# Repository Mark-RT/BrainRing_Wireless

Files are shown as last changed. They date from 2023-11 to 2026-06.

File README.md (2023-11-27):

# BrainRing_Wireless

Разработка для игры BrainRing - беспроводная версия. Количество участников может быть не больше 10, в основном 4. Для устройства ведущего есть прошивка "Admin", а для всех участников прошивка "Players".

Устройства работают на принципе обратной связи, постоянной. То есть Игроки в любой момент времени, даже если была перезагрузка или потеря связи, знают, выиграли они или нет. Этот принцип конечно идёт в ущерб энергопотреблению, но в плюс стабильности работы, так как проверено временем.

По какой-то причине 1 версия перестала работать. Есть подозрение что обновилась библиотека и что-то пошло не так. Поэтому 2-я версия усовершенствованная (иногда были проблемы что игроки вместе нажимали на кнопку и ни у кого не сработало) и на всякий случай оставляю библиотеку которая точно работала на момент загрузки кода.











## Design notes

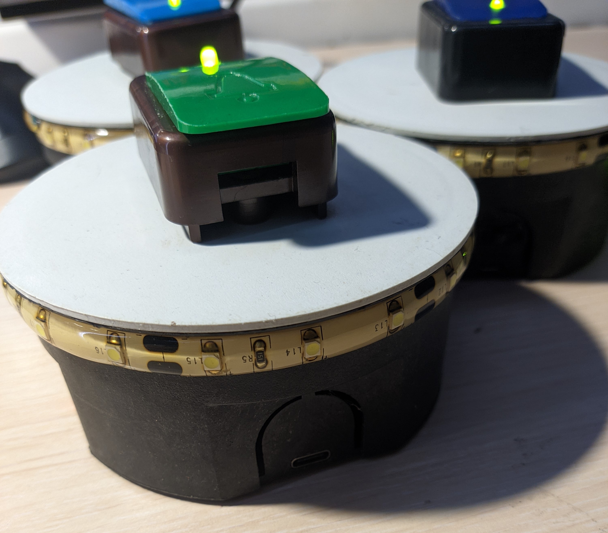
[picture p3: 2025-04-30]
images/IMG_20231107_213945_8.4.300.jpg

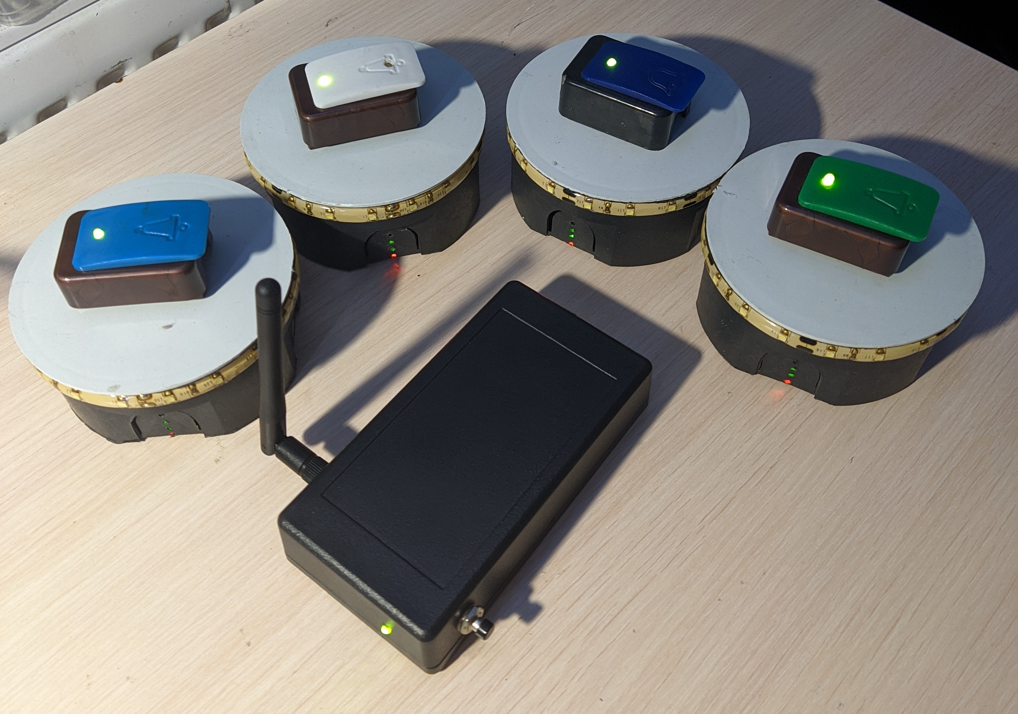
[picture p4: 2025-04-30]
images/IMG_20231107_213823_8.4.300.jpg

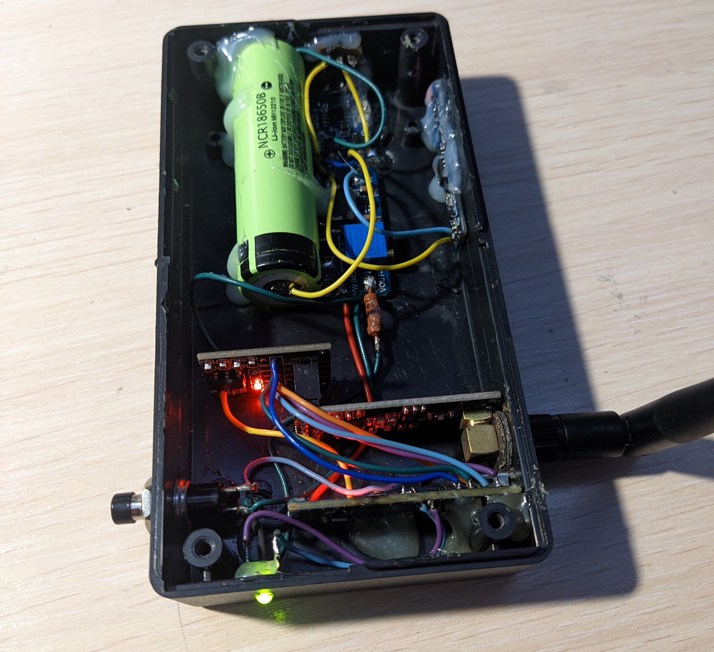
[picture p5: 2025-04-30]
images/IMG_20231107_214144_8.4.300.jpg

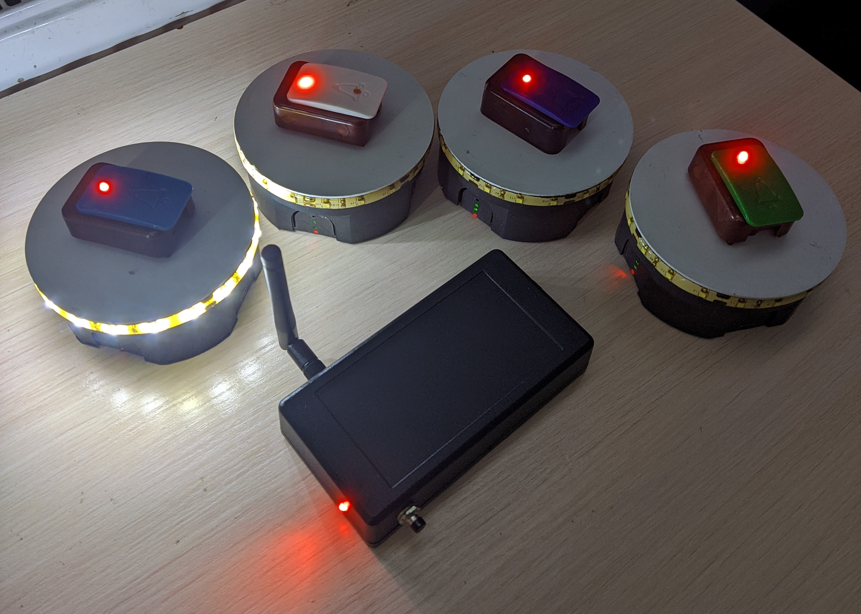
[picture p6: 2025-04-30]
images/IMG_20231107_215251_8.4.300.jpg

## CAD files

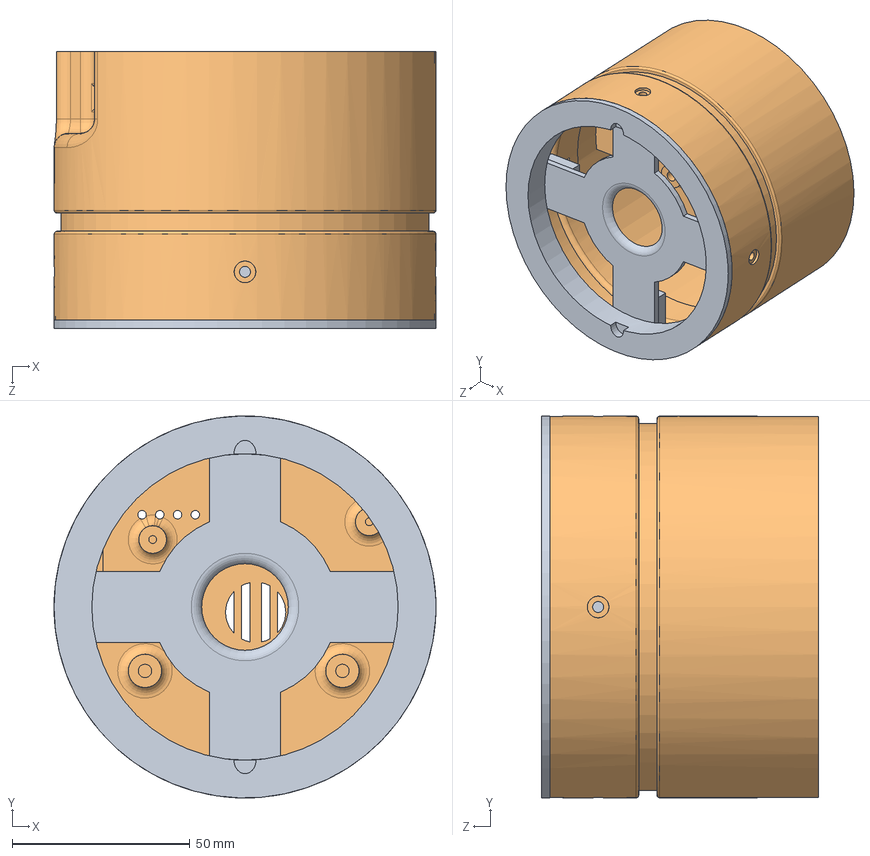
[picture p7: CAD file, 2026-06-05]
3D/Players/BOX_PLAYERS.SLDASM
107.6 x 107.6 x 77.9 mm
Box_BRw_players
Cap_BRw_players

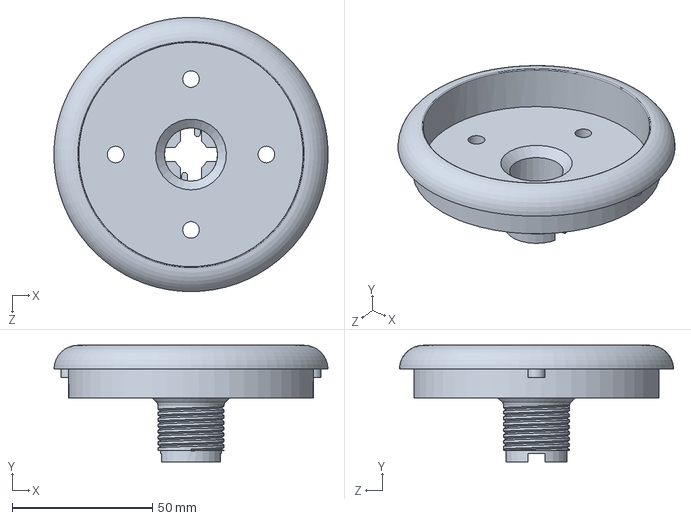
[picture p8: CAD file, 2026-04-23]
3D/Players/Elements/Copy of Thredded Base^100mm BigButton Assy.SLDPRT
97.5 x 41.5 x 97.6 mm

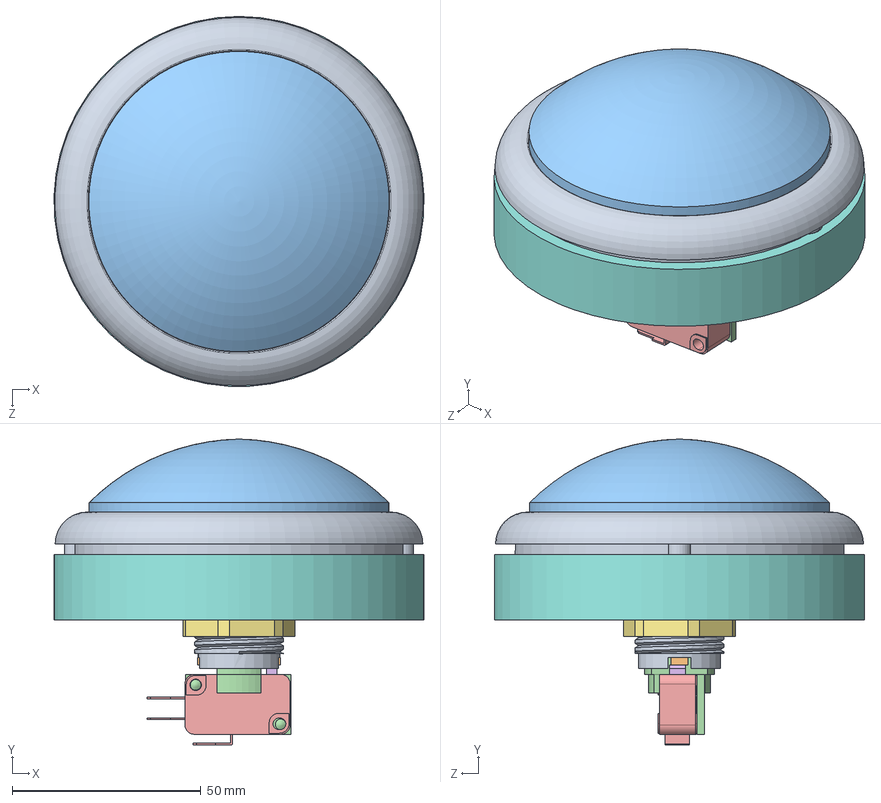
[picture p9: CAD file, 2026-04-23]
3D/Players/Elements/100mm BigButton Assy.SLDASM
98.1 x 81.1 x 98.1 mm
Copy of Thredded Base^100mm BigButton Assy
Copy of InnerDome^100mm BigButton Assy
Copy of GR_Dome^100mm BigButton Assy
Copy of LED_switch_Holder^100mm BigButton Assy
AceMaker Switch
Red Dome
Copy of Nut^100mm BigButton Assy
Copy of Dish^100mm BigButton Assy

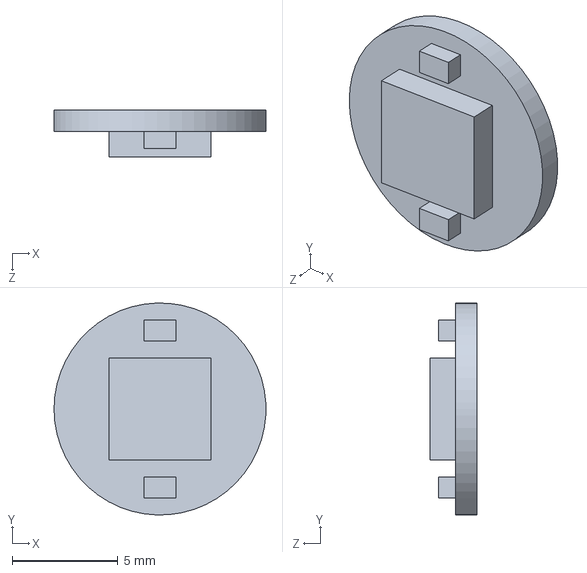
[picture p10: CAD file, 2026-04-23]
3D/Admin/Elements_admin/WS2812b_1_round_pcb.SLDPRT
10.0 x 10.00 x 2.20 mm

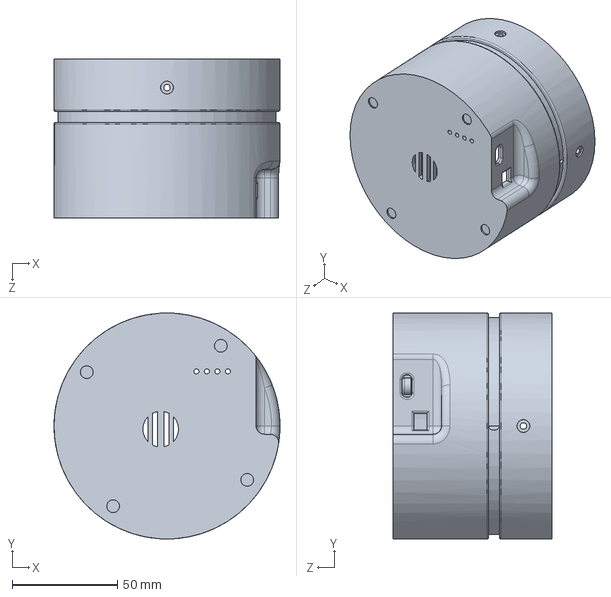
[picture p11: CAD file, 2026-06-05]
3D/Players/Box_BRw_players.SLDPRT
107.6 x 107.6 x 75.5 mm

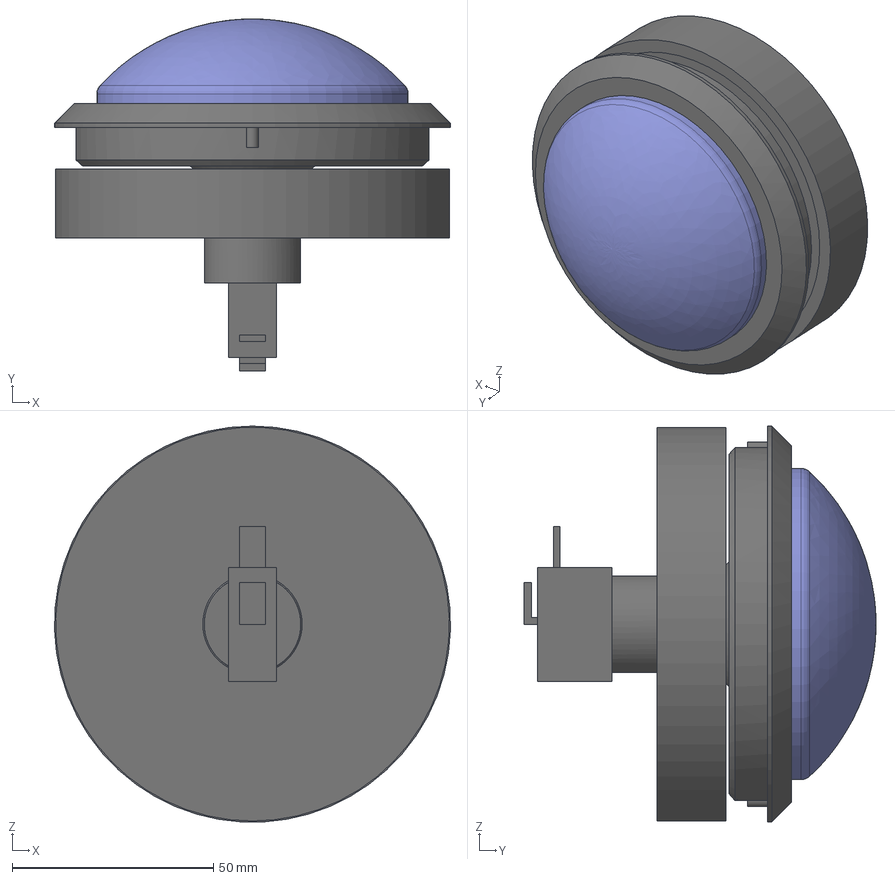
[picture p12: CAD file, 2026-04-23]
3D/Players/Elements/Massive_Arcade_Button_with_LED_-_100mm_Red.step
98.5 x 87.5 x 98.4 mm

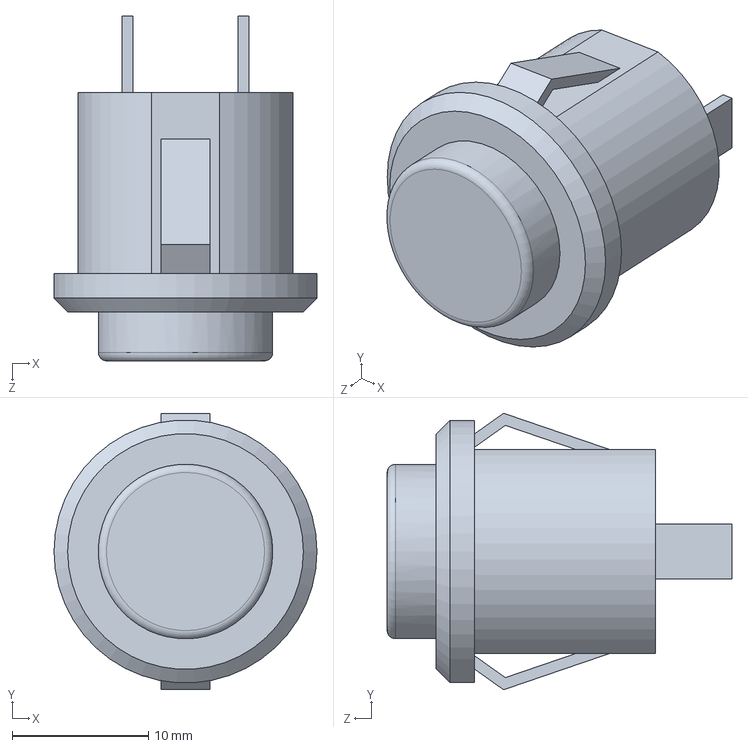
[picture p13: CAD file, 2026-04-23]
3D/Admin/Elements_admin/Push_Button_20mm.SLDPRT
19.3 x 20.3 x 25.3 mm

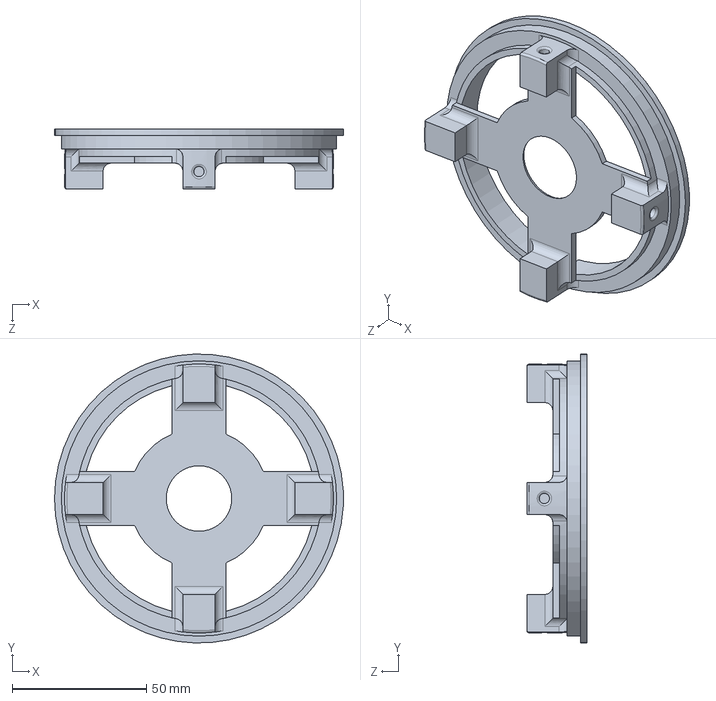
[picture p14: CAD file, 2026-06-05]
3D/Players/Cap_BRw_players.SLDPRT
107.6 x 107.6 x 22.4 mm

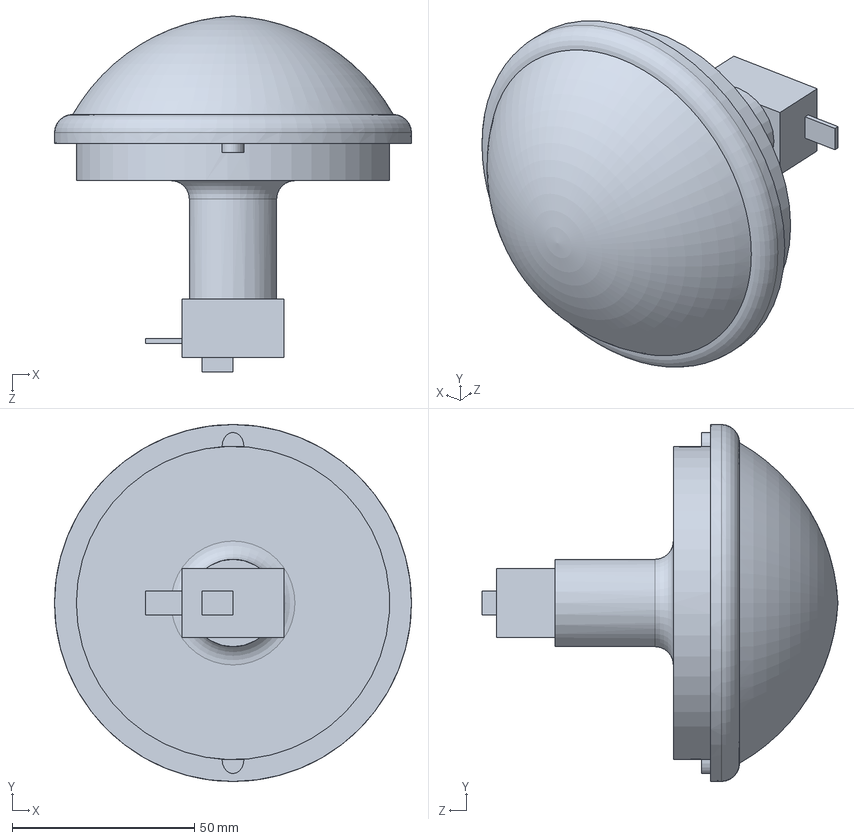
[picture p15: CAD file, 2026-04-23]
3D/Players/Elements/Arcade_Button_100mm.SLDPRT
98.0 x 98.0 x 97.7 mm

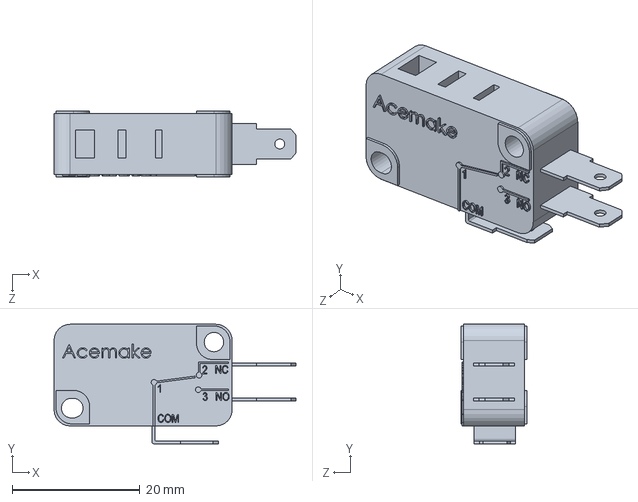
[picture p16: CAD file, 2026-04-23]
3D/Players/Elements/AceMaker Switch.SLDPRT
37.9 x 18.7 x 10.3 mm

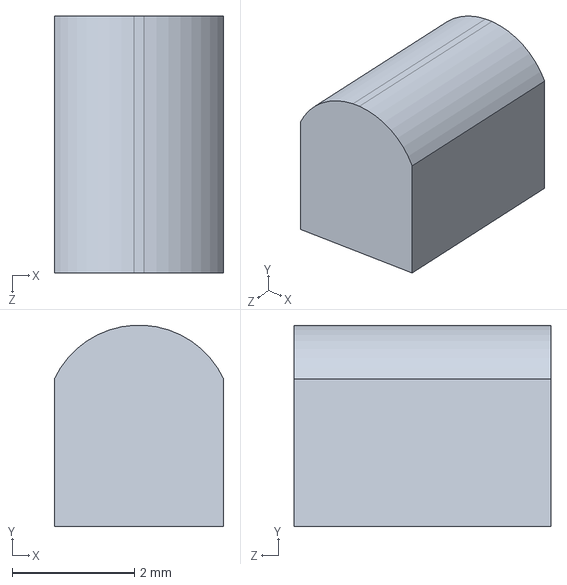
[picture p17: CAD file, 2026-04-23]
3D/Players/Elements/Red Dome.SLDPRT
2.77 x 3.29 x 4.20 mm

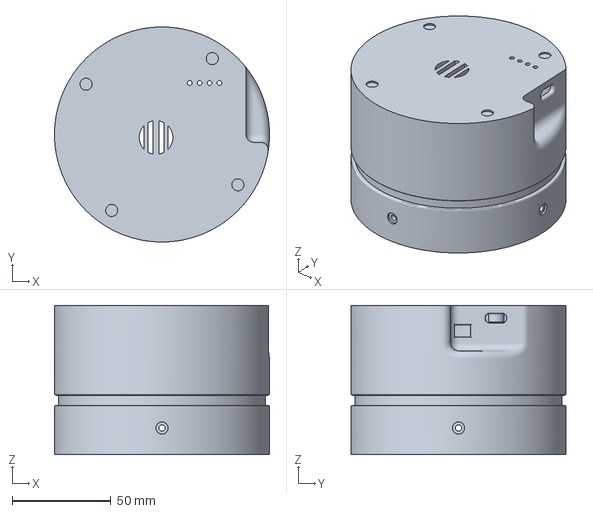
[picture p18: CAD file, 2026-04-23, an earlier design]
3D/Players/print/v1/Box_BRw_players.3MF
108.6 x 108.6 x 75.5 mm

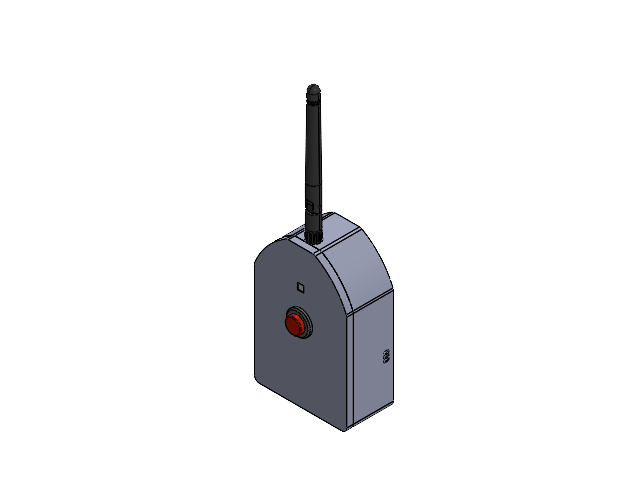
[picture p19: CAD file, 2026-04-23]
3D/Admin/Box_Admin.SLDASM
LGT8F328P_LQFP32~pcb~cXTa_1.step
LGT8F328P_LQFP32~pcb~cXTa-0_1.step
LGT8F328P_LQFP32~pcb~cXTa-1_1.step
LGT8F328P_LQFP32~pcb~cXTa-2_1.step
LGT8F328P_LQFP32~pcb~cXTa-3_1.step
LGT8F328P_LQFP32~pcb~cXTa-4_1.step
LGT8F328P_LQFP32~pcb~cXTa-5_1.step
LGT8F328P_LQFP32~pcb~cXTa-6_1.step
Board~cXTa_1.step
Antenna base_1.step
Antenna top_1.step
NRF24L01L_1.step
500SSP1S1M6QEA--3DModel-STEP-520916_1.step
Body_1.step
Pins_1.step
BH-18650-PC_1.step
JST_EH_B4B-EH-A_1x04_P2.50mm_Vertical_1.step
C_0805_2012Metric_1.step x 9
LED_0805_2012Metric_1.step x 4
R_0603_1608Metric_1.step x 6
HSOP-8-1EP_3.9x4.9mm_P1.27mm_EP2.41x3.1mm_1.step
D_SMA_1.step
SOT-223_1.step
USB_C_Receptacle_GCT_USB4125-xx-x_6P_TopMnt_Horizontal.step
SOT-23_1.step
L_APV_APH0630_1.step
BrainRing_Wireless_Admin_PCB_1.step
Push_Button_20mm
WS2812b_1_round_pcb
Case_BRw_admin
Cap_BRw_admin

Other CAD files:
3D/Players/print/v2/Box_BRw_players.STEP
3D/Admin/Cap_BRw_admin.SLDPRT
3D/Players/print/v2/Cap_BRw_players.STEP
3D/Admin/Case_BRw_admin.SLDPRT
3D/Players/print/v1/Cap_BRw_players.3MF
3D/Players/print/v1/Box_BRw_players.STL
3D/Players/print/v1/Cap_BRw_players.STL

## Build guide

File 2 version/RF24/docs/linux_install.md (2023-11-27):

# Linux Installation

@tableofcontents

<!-- markdownlint-disable MD031 -->
Generic Linux devices are supported via SPIDEV, MRAA, RPi native via BCM2835, or using LittleWire.

@note The SPIDEV option should work with most Linux systems supporting spi userspace device.

@warning These install instructions are beginning to age because they were designed with the assumption that
the arm-linux-gnueabihf-g\*\* compilers were available and default for the system. If you have problems
using the manual install instructions (especially on a 64-bit OS), please try the
[instructions using CMake](md_docs_using_cmake.html).

@note Since wiringPi is no longer maintained or distributed (as of RPi OS 11 bullseye),
pigpio is now required for using the radio's IRQ pin. This applies to RPi, SPIDEV, and pigpio drivers. The MRAA driver may provide its own IRQ implementation. Remember that the RPi OS lite variant does not ship with pigpio installed.

## Automated Install

**Designed & Tested on RPi** - Defaults to SPIDEV on devices supporting it

1. Install prerequisites if there are any (pigpio, MRAA, LittleWire libraries, setup SPI device etc)
2. Download the install.sh file from [http://tmrh20.github.io/RF24Installer/RPi/install.sh](http://tmrh20.github.io/RF24Installer/RPi/install.sh)
   ```shell
   wget http://tmrh20.github.io/RF24Installer/RPi/install.sh
   ```
3. Make it executable
   ```shell
   chmod +x install.sh
   ```
4. Run it and choose your options
   ```shell
   ./install.sh
   ```
5. Run an example from one of the libraries
   ```shell
   cd rf24libs/RF24/examples_linux
   ```
   Edit the gettingstarted example, to set your pin configuration
   ```shell
   nano gettingstarted.cpp
   make
   sudo ./gettingstarted
   ```

## Manual Install

1. Install prerequisites if there are any (pigpio, MRAA, LittleWire libraries, setup SPI device etc)
   @note See the [MRAA](http://iotdk.intel.com/docs/master/mraa/index.html) documentation for more info on installing MRAA
2. Make a directory to contain the RF24 and possibly RF24Network lib and enter it
   ```shell
   mkdir ~/rf24libs
   cd ~/rf24libs
   ```
3. Clone the RF24 repo
   ```shell
   git clone https://github.com/tmrh20/RF24.git RF24
   ```
4. Change to the new RF24 directory
   ```shell
   cd RF24
   ```
5. Configure build environment using
   ```shell
   ./configure
   ```
   script. It auto detectes device and build environment.

   For overriding autodetections, use command-line switches, see
   ```shell
   ./configure --help
   ```
   for description.
6. Build the library, and run an example file
   ```shell
   make
   sudo make install
   ```
   ```shell
   cd examples_linux
   ```
   Edit the gettingstarted example, to set your pin configuration
   ```shell
   ano gettingstarted.cpp
   make
   sudo ./gettingstarted
   ```

### Build using SPIDEV

1. Make sure that spi device support is enabled and /dev/spidev\<a\>.\<b\> is present
2. Manual Install using SPIDEV:
   ```shell
   ./configure --driver=SPIDEV
   make
   sudo make install
   ```
3. See the gettingstarted example for an example of pin configuration

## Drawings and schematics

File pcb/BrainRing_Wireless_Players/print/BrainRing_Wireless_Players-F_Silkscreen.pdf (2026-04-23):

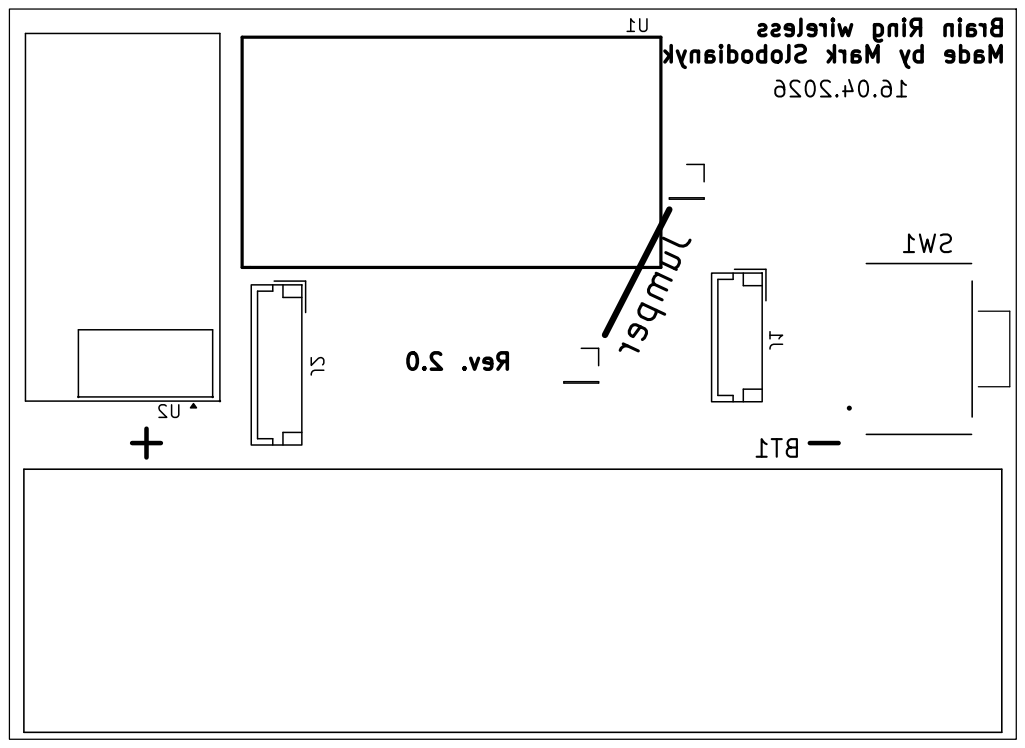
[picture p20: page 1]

2.0 Rev. 16.04.2026 wireless Ring Brain Slobodianyk Mark by Made Jumper

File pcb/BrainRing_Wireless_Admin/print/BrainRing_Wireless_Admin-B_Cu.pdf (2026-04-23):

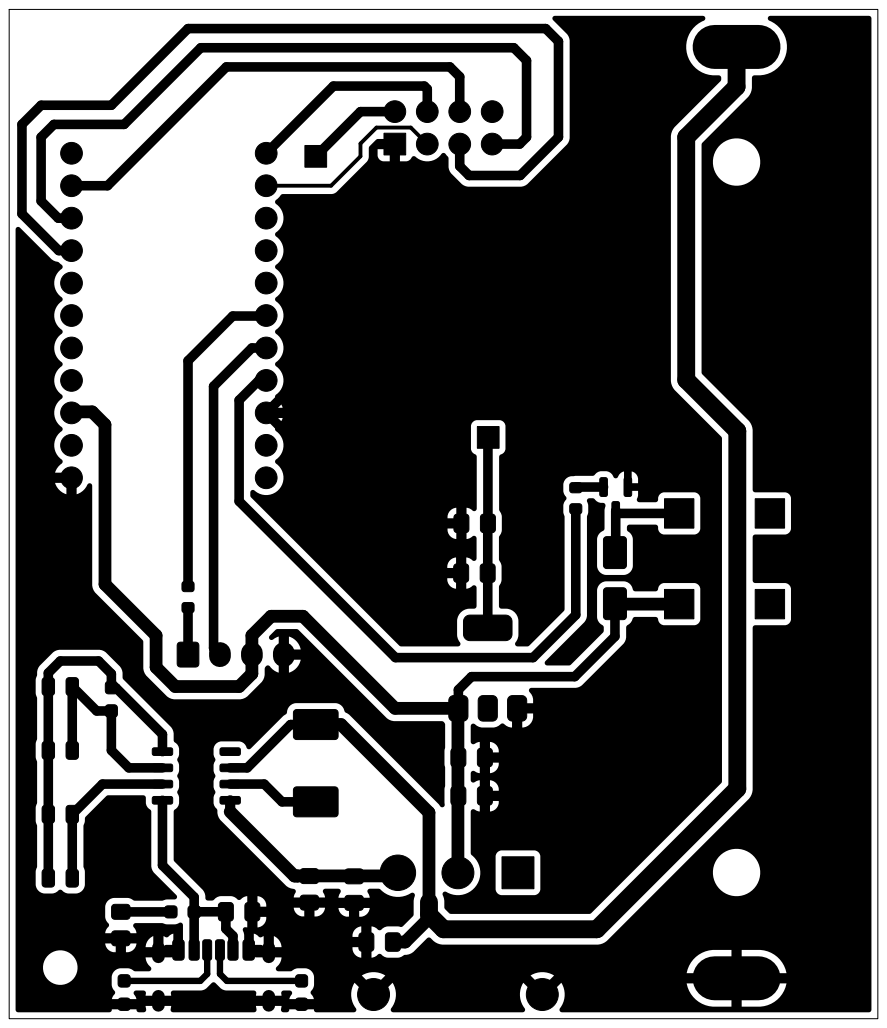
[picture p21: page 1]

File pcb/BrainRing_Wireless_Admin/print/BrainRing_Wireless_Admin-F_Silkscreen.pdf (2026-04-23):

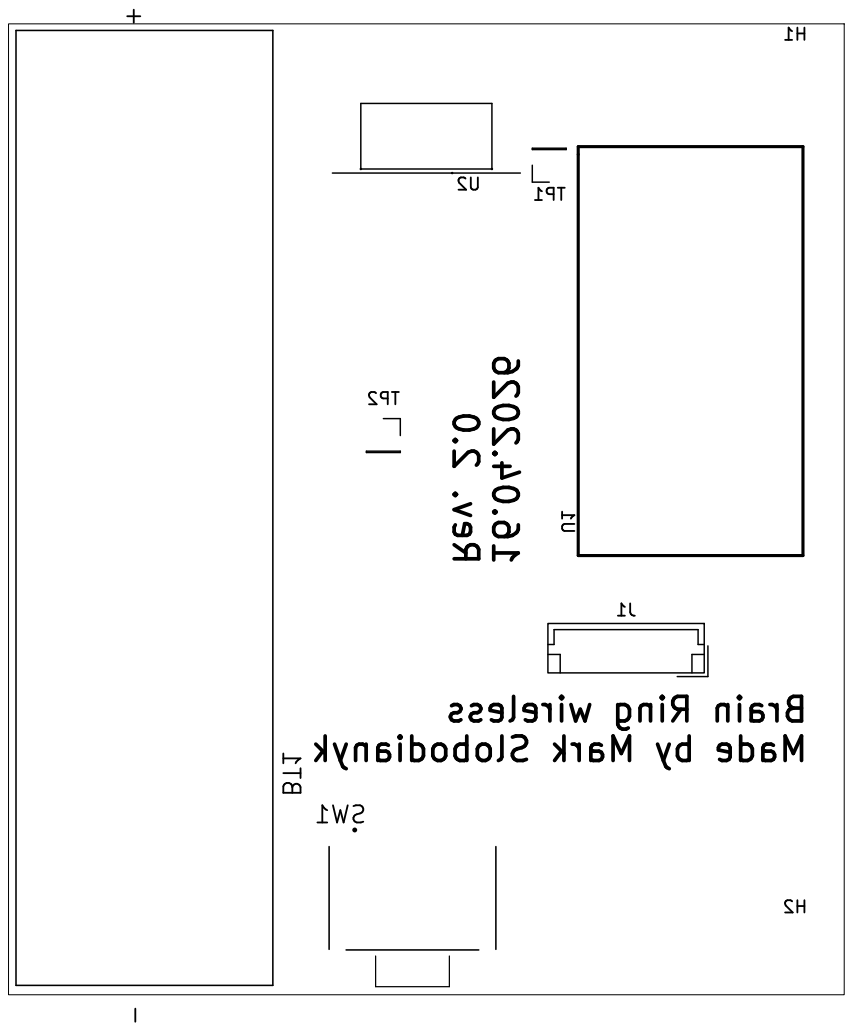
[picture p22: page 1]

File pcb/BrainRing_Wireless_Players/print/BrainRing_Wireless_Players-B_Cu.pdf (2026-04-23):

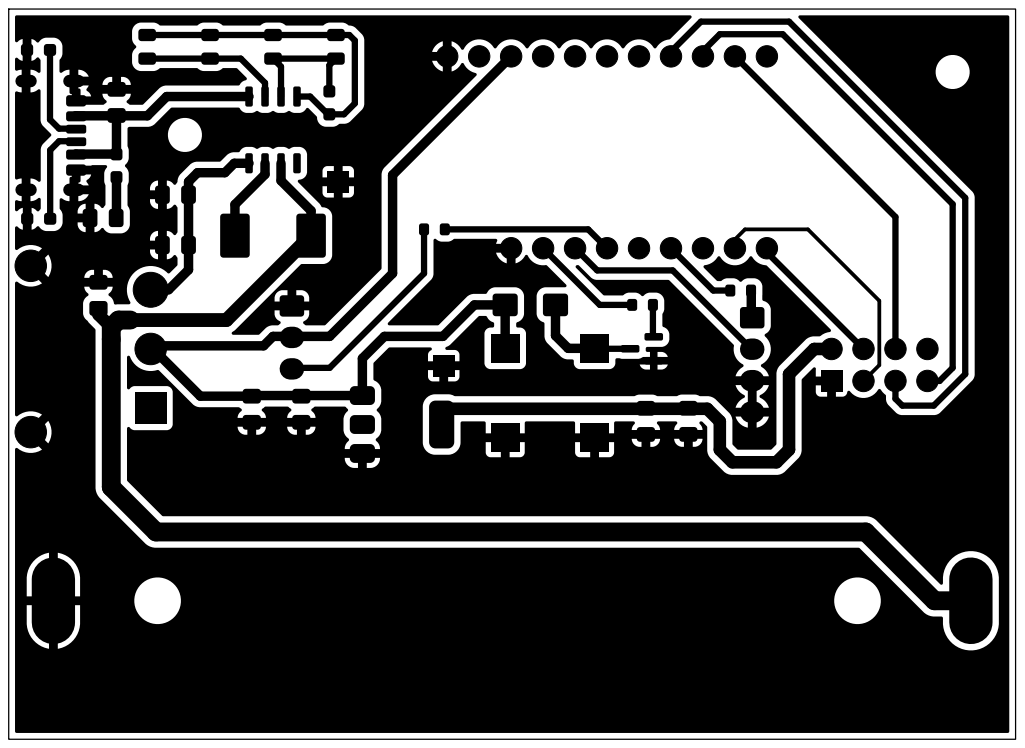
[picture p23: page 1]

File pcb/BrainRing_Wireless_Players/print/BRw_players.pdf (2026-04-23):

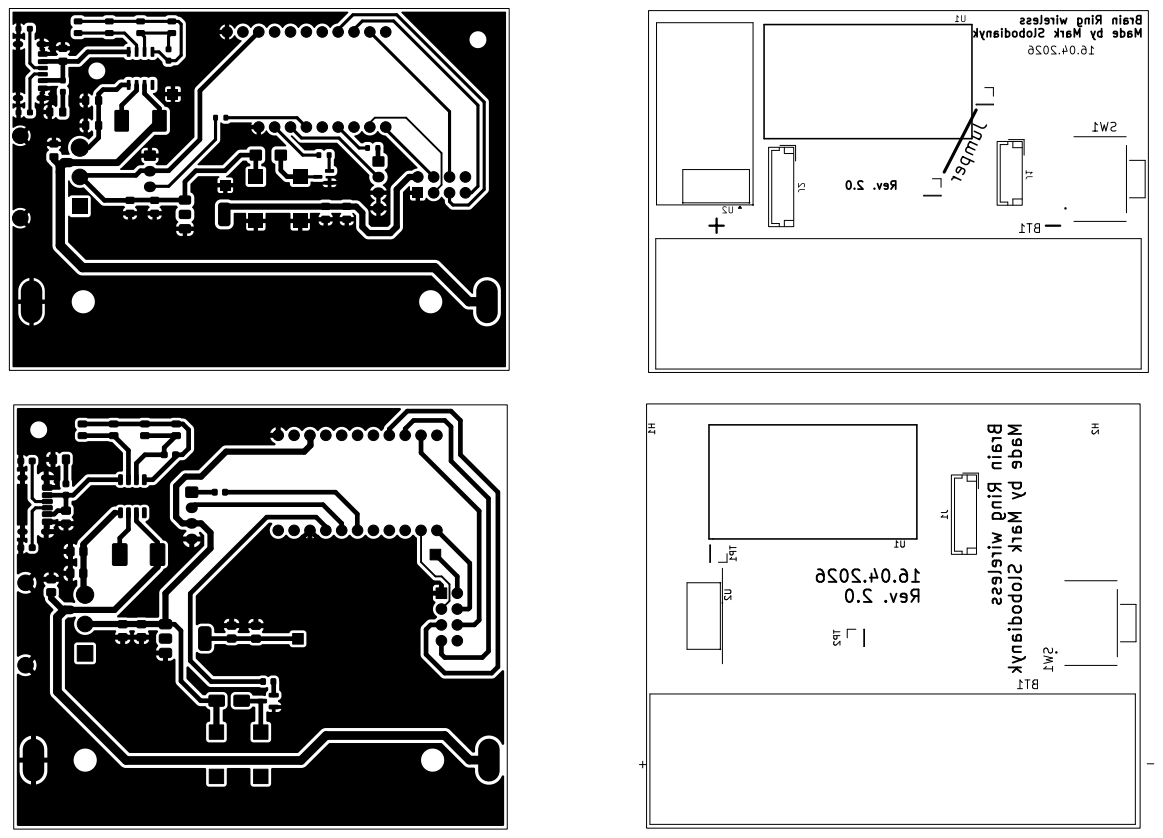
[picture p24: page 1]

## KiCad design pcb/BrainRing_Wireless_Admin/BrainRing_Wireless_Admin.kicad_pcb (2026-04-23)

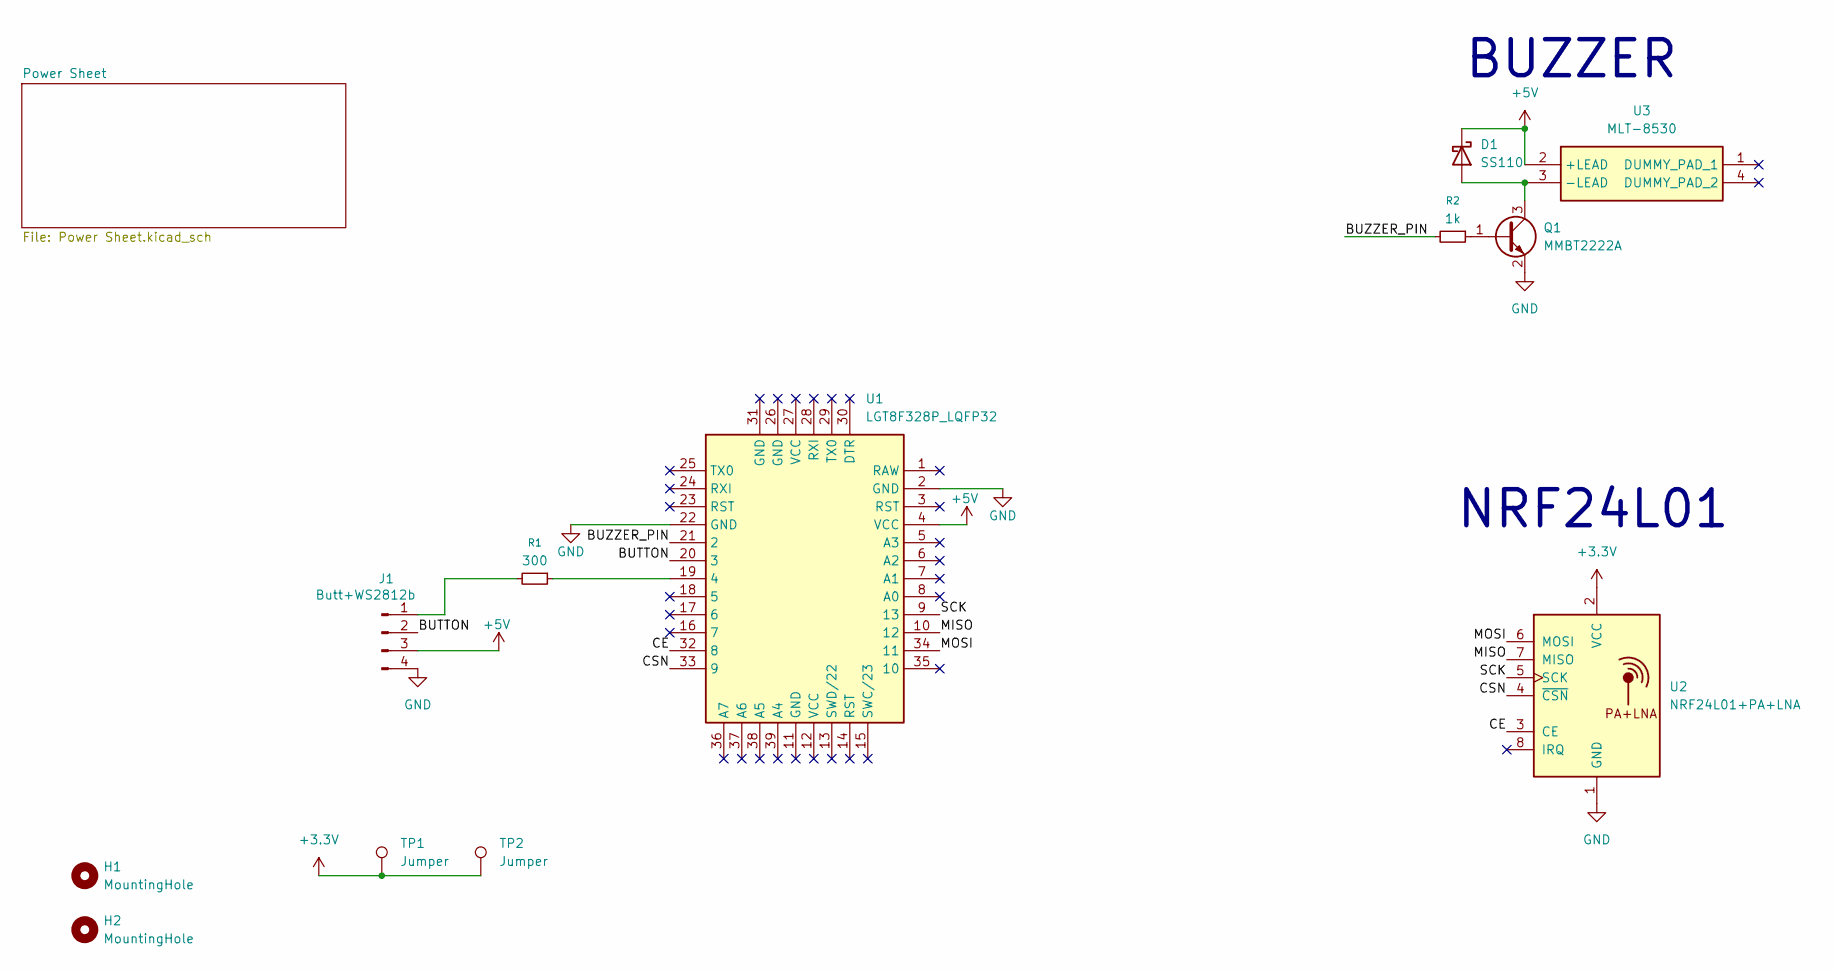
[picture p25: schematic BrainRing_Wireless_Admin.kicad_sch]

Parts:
D1: SS110; D_SMA
H1, H2: MountingHole; MountingHole_2.2mm_M2
J1: Butt+WS2812b; JST_EH_B4B-EH-A_1x04_P2.50mm_Vertical
Q1: MMBT2222A; SOT-23
R1: 300; R_0603_1608Metric
R2: 1k; R_0603_1608Metric
TP1, TP2: Jumper; PinHeader_1x01_P2.54mm_Vertical
U1: LGT8F328P_LQFP32; Manufacturer Part New SchematicLib
U2: NRF24L01+PA+LNA; nRF24L01+PA+LNA_Breakout
U3: MLT-8530; MLT8530; Manufacturer_Part_Number MLT-8530

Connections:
+3.3V: TP1.1, TP2.1, U2.2 (VCC); also elsewhere on the board
+5V: D1.1 (K), J1.3, U1.4 (VCC), U3.2 (+LEAD); also elsewhere on the board
/BUTTON: J1.2, U1.20 (3)
/BUZZER_PIN: R2.2, U1.21 (2)
/CE: U1.32 (8), U2.3 (CE)
/CSN: U1.33 (9), U2.4 (~CSN)
/MISO: U1.10 (12), U2.7 (MISO)
/MOSI: U1.34 (11), U2.6 (MOSI)
/SCK: U1.9 (13), U2.5 (SCK)
GND: J1.4, Q1.2 (E), U1.2 (GND), U1.22 (GND), U2.1 (GND); also elsewhere on the board
unnamed: D1.2 (A), Q1.3 (C), U3.3 (-LEAD)
unnamed: J1.1, R1.2
unnamed: Q1.1 (B), R2.1
unnamed: R1.1, U1.19 (4)

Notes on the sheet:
BUZZER
NRF24L01

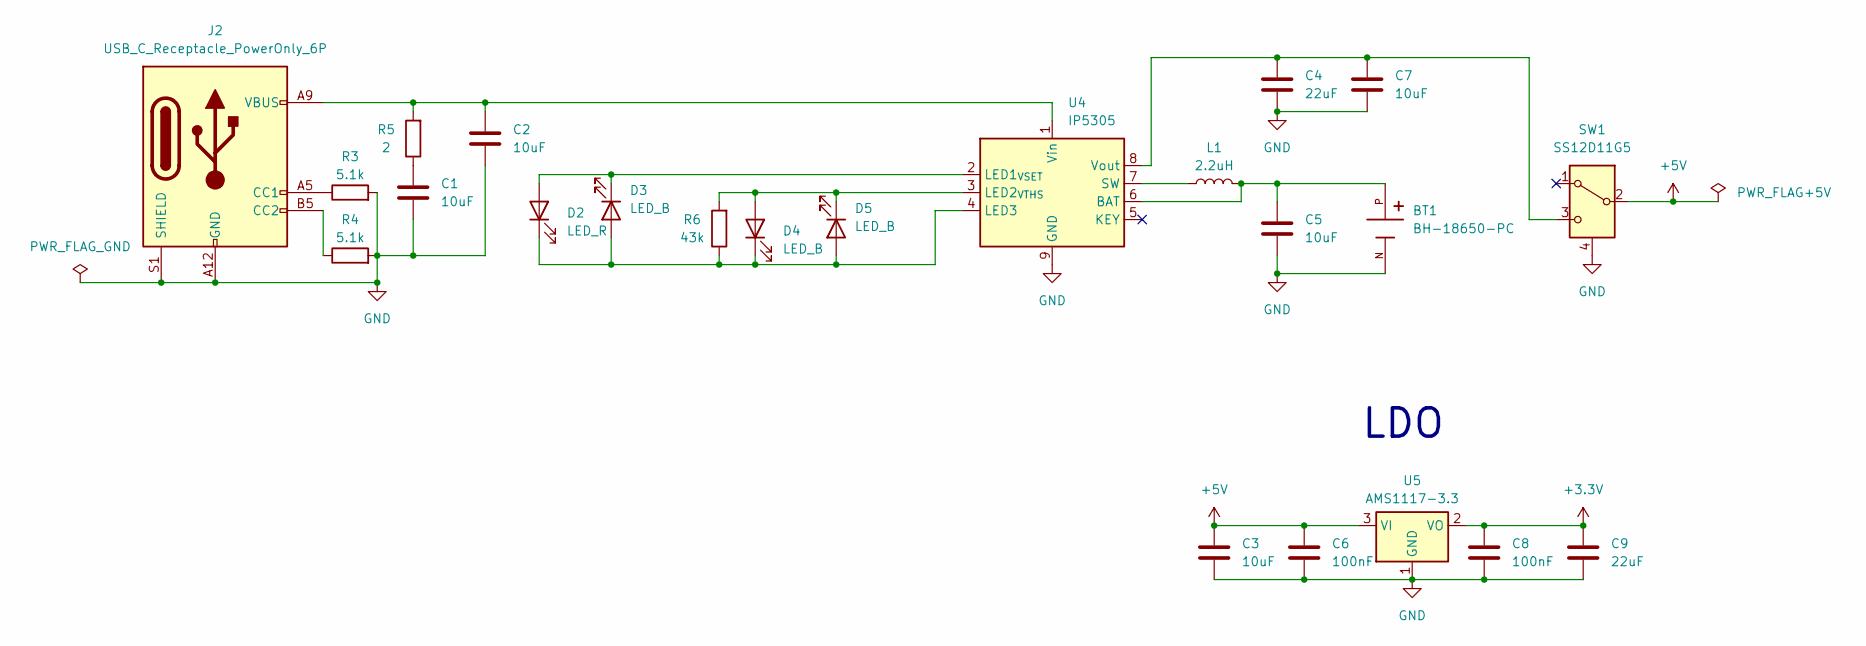
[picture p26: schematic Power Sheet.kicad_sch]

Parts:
BT1: BH-18650-PC; BAT_BH-18650-PC
C1, C2, C3, C5, C7: 10uF; C_0805_2012Metric_Pad1.18x1.45mm_HandSolder
C4, C9: 22uF; C_0805_2012Metric_Pad1.18x1.45mm_HandSolder
C6, C8: 100nF; C_0805_2012Metric_Pad1.18x1.45mm_HandSolder
D2: LED_R; LED_0805_2012Metric
D3, D4, D5: LED_B; LED_0805_2012Metric
J2: USB_C_Receptacle_PowerOnly_6P; USB_C_Receptacle_HRO_TYPE-C-31-M-17
L1: 2.2uH; L_APV_APH0630
R3, R4: 5.1k; R_0603_1608Metric_Pad0.98x0.95mm_HandSolder
R5: 2; R_0603_1608Metric_Pad0.98x0.95mm_HandSolder
R6: 43k; R_0603_1608Metric_Pad0.98x0.95mm_HandSolder
SW1: SS12D11G5
U4: IP5305; HSOP-8-1EP_3.9x4.9mm_P1.27mm_EP2.41x3.1mm
U5: AMS1117-3.3; SOT-223-3_TabPin2

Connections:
+3.3V: C8.1, C9.1, U5.2 (VO); also elsewhere on the board
+5V: C3.1, C6.1, SW1.2 (B), U5.3 (VI); also elsewhere on the board
GND: BT1.N, C1.2, C2.2, C3.2, C4.2, C5.2, C6.2, C7.2, C8.2, C9.2, J2.A12 (GND), J2.B12 (GND), J2.S1 (SHIELD), R3.2, R4.2, SW1.4 (Shield), U4.9 (GND), U5.1 (GND); also elsewhere on the board
unnamed: C1.1, R5.1
unnamed: D2.2 (A), D3.1 (K), U4.2 (LED1_{VSET})
unnamed: D2.1 (K), D3.2 (A), D4.1 (K), D5.2 (A), R6.1, U4.4 (LED3)
unnamed: D4.2 (A), D5.1 (K), R6.2, U4.3 (LED2_{VTHS})
unnamed: J2.A5 (CC1), R3.1
unnamed: J2.B5 (CC2), R4.1
unnamed: C4.1, C7.1, SW1.3 (C), U4.8 (Vout)
unnamed: BT1.P, C5.1, L1.2, U4.6 (BAT)
unnamed: L1.1, U4.7 (SW)
unnamed: C2.1, J2.A9 (VBUS), J2.B9 (VBUS), R5.2, U4.1 (Vin)

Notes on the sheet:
LDO

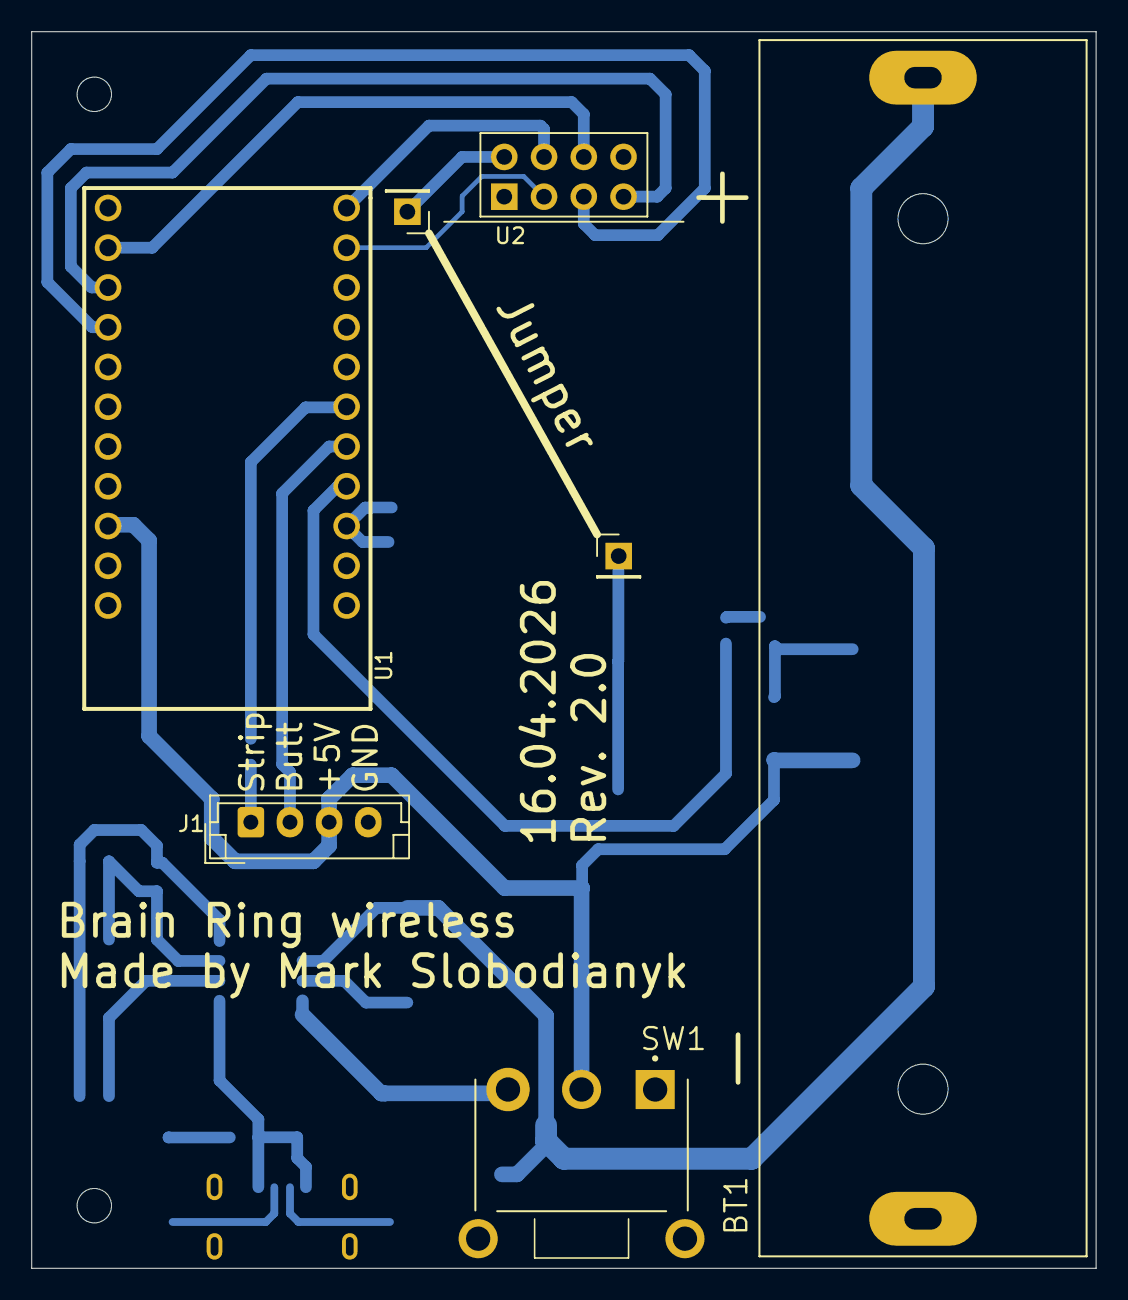
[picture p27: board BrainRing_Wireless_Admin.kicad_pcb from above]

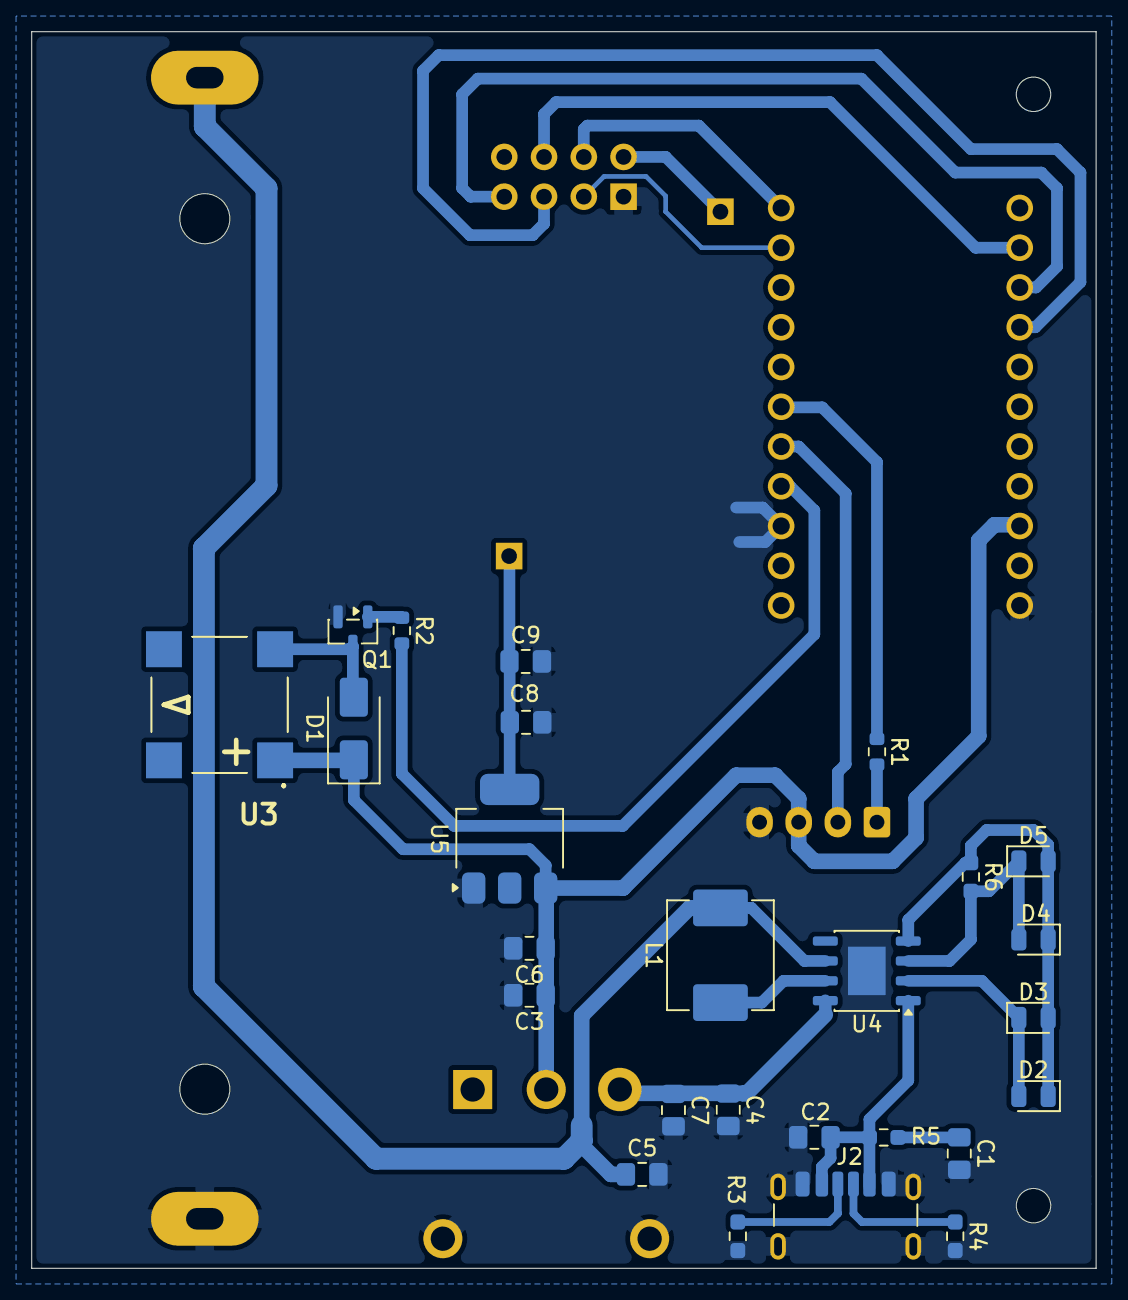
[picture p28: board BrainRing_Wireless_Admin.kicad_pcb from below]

Board: 2 copper layers, 68.0 x 79.0 mm, 35 parts (26 on the bottom side), 24 nets.

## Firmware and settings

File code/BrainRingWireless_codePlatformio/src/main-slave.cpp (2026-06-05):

#include <Arduino.h>

#define PLAYER_ID 1 // Уникальный ID игрока (1 - 5)
// 1-Красный, 2-Зеленый, 3-Синий, 4-Желтый, 5-Белый

#include <SPI.h>
#include <RF24.h>
#define CE_PIN 8
#define CSN_PIN 9
RF24 radio(CE_PIN, CSN_PIN);
byte address[][6] = {"Admin", "Node1"}; // Адреса труб

#define PIN_LED_STRIP 4 // Лента WS2812B
#define NUM_LEDS 20     // Кол-во диодов в ленте
#define COLOR_DEPTH 3
#include <microLED.h> // подключаем библу
microLED<NUM_LEDS, PIN_LED_STRIP, MLED_NO_CLOCK, LED_WS2818, ORDER_GRB, CLI_AVER> strip;
// Массив базовых цветов microLED (тип данных mData)
mData playerColors[5] = {mRed, mGreen, mBlue, mYellow, mWhite};
mData myColor;

// --- ПИНЫ ---
#define PIN_BUZZER 2  // Пассивный бузер
#define PIN_BUTTON 3  // Аркадная кнопка
#define PIN_BTN_LED 6 // Светодиод внутри кнопки (через резистор)

// Системные переменные
unsigned long lastPingTime = 0;
const int PING_INTERVAL = 100; // Как часто опрашиваем Админа (в миллисекундах)

// --- НАСТРОЙКИ АСИНХРОННОЙ МЕЛОДИИ ---
// 0 в массиве частот означает тишину (паузу)
const int winFreq[] = {800, 0, 1200, 0, 1500};
const int winDur[] = {100, 50, 200, 50, 300};
const int winTotalNotes = 5;

int currentNote = 0;
unsigned long noteTimer = 0;
bool isPlaying = false;

// Состояния стейт-машины
enum State
{
  STATE_IDLE,
  STATE_WON,
  STATE_BLOCKED
};
State currentState = STATE_IDLE;

volatile bool buttonHit = false; // Флаг мгновенного нажатия
volatile unsigned long lastBtnTime = 0;
void isrButton()
{
  // Если статус IDLE и с прошлого нажатия прошло больше хх мс
  if (currentState == STATE_IDLE && (millis() - lastBtnTime > 60))
  {
    buttonHit = true;
    lastBtnTime = millis();
  }
}

// Запуск мелодии с самого начала
void startWinSequence()
{
  currentNote = 0;
  isPlaying = true;
  noteTimer = millis();

  if (winFreq[0] > 0)
  {
    noTone(PIN_BUZZER);           // Глушим старый звук для надежности
    tone(PIN_BUZZER, winFreq[0]); // БЕЗ 3-ГО АРГУМЕНТА!
  }
}

void stopBuzzer()
{
  isPlaying = false;
  noTone(PIN_BUZZER);
}

void handleMelody()
{
  if (!isPlaying)
    return;

  if (millis() - noteTimer >= winDur[currentNote])
  {
    currentNote++;

    if (currentNote < winTotalNotes)
    {
      noteTimer = millis();
      if (winFreq[currentNote] > 0)
      {
        noTone(PIN_BUZZER);                     // Сброс глюка ядра LGT8F
        tone(PIN_BUZZER, winFreq[currentNote]); // БЕЗ 3-ГО АРГУМЕНТА!
      }
      else
      {
        noTone(PIN_BUZZER); // Отрабатываем паузу (0 в массиве)
      }
    }
    else
    {
      isPlaying = false;
      noTone(PIN_BUZZER); // Глушим окончательно
    }
  }
}

// Функция управления светом и звуком при смене состояний
void applyStateVisuals()
{
  if (currentState == STATE_IDLE)
  {
    // Раунд сброшен, всё гасим, готовы к нажатию
    digitalWrite(PIN_BTN_LED, HIGH);
    strip.clear(); // очистка буфера (выключить диоды, чёрный цвет)
    strip.show();  // вывод изменений на ленту
    delay(1);
    stopBuzzer(); // <--- Обрываем звук, если нажали Сброс
  }
  else if (currentState == STATE_WON)
  {
    // Мы победили! Включаем наш цвет на максимум
    digitalWrite(PIN_BTN_LED, HIGH);
    strip.fill(myColor); // заливаем цветом игрока
    strip.show();        // выводим изменения
    delay(1);
    startWinSequence(); // <--- Асинхронно запускаем победную мелодию
  }
  else if (currentState == STATE_BLOCKED)
  {
    // Нажал кто-то другой.
    digitalWrite(PIN_BTN_LED, LOW);
    stopBuzzer(); // <--- Для надежности тоже глушим звук
  }
}

// Функция смены текущего состояния с защитой от ложных срабатываний
void changeState(State newState)
{
  if (currentState != newState)
  {
    currentState = newState;
    applyStateVisuals(); // Обновляем индикацию только если статус реально изменился
  }
}

// Отправка пакета Админу и мгновенная обработка ответа (ACK Payload)
void sendToAdmin(byte dataToSend)
{
  if (radio.write(&dataToSend, sizeof(dataToSend)))
  {
    Serial.println("send");
    // Serial.print(txData[0]);
  }
  else
    Serial.println("fail");

  if (radio.isAckPayloadAvailable())
  {
    byte globalState;
    radio.read(&globalState, sizeof(globalState));

    // Анализируем ответ Админа (0 = Идет игра, 1-5 = Номер победителя)
    if (globalState == 0)
    {
      changeState(STATE_IDLE);
    }
    else if (globalState == PLAYER_ID)
    {
      changeState(STATE_WON);
    }
    else
    {
      changeState(STATE_BLOCKED);
    }
  }
}

void setup()
{
  Serial.begin(57600);

  // ===== NRF24L01 =====
  radio.begin();
  radio.setChannel(0x60);
  radio.setDataRate(RF24_1MBPS);
  radio.setPALevel(RF24_PA_MAX);
  radio.setRetries(5, 10);
  radio.enableAckPayload();
  radio.openWritingPipe(address[0]);
  radio.powerUp();
  radio.stopListening();

  // ===== WS2812 =====
  if (PLAYER_ID >= 1 && PLAYER_ID <= 5)
    myColor = playerColors[PLAYER_ID - 1];
  else
    myColor = mWhite;
  strip.setBrightness(100);
  strip.clear(); // очистка буфера (выключить диоды, чёрный цвет)
  strip.show();  // вывод изменений на ленту
  delay(1);      // между вызовами show должна быть пауза минимум 40 мкс !!!!

  pinMode(PIN_BTN_LED, OUTPUT);
  pinMode(PIN_BUZZER, OUTPUT);
  pinMode(PIN_BUTTON, INPUT_PULLUP);

  attachInterrupt(digitalPinToInterrupt(PIN_BUTTON), isrButton, FALLING);
}

void loop()
{
  if (buttonHit) // 1. ПРИОРИТЕТ: Игрок ударил по кнопке
  {
    Serial.println("Press");
    buttonHit = false;
    sendToAdmin(PLAYER_ID); // Отправляем Админу свой боевой ID (я нажал!)
  }

  if (millis() - lastPingTime > PING_INTERVAL) // 2. ФОНОВЫЙ ОПРОС: Синхронизация статуса (Пинг)
  {
    lastPingTime = millis();
    if (!buttonHit) // Если по кнопке сейчас не бьют, отправляем Админу код 0 (просто спросить статус)
      sendToAdmin(0);
  }

  // Асинхронный обработчик звука
  handleMelody();
}

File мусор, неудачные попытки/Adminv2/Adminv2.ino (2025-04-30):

#include <SPI.h>
#include <nRF24L01.h>
#include <RF24.h>
RF24 radio(9, 10);

#define button 5  //главная кнопка
#define green_led 6
#define red_led 7

int myData[1];
int ackData[1];
int txData[1];

byte butt;
bool butt_flag = 0;
byte value = 0;
bool check_flag = 0;
void setup() {
  Serial.begin(9600);
  radio.begin           ();
  radio.setChannel      (0x4c);
  radio.setDataRate     (RF24_2MBPS);
  radio.setPALevel      (RF24_PA_MAX);
  radio.enableAckPayload();
  radio.enableDynamicPayloads();

  radio.openReadingPipe (0, 0xAABBCCDD11LL);
  radio.openReadingPipe (1, 0xAABBCCDD22LL);
  radio.openReadingPipe (2, 0xAABBCCDD33LL);
  radio.openReadingPipe (3, 0xAABBCCDD44LL);
  radio.startListening  ();

  pinMode(button, INPUT_PULLUP);  //подключение кнопки
  pinMode(red_led, OUTPUT);      //подключение красного светодиода
  pinMode(green_led, OUTPUT);      //подключение зеленого светодиода
  digitalWrite(green_led, 1);
}

void loop() {
  if (radio.available()) {
    radio.read(&myData, sizeof(myData));
    Serial.println(myData[0]);
    switch (myData[0]) {
      case 1:
        if (!check_flag) {
          check_flag = 1;
          ackData[0] = myData[0] * 11;
          radio.writeAckPayload (myData[0] - 1, &ackData, sizeof(ackData));
          value = 15;
          digitalWrite(red_led, 1);
          digitalWrite(green_led, 0);
        }
        break;

      case 2:
        if (!check_flag) {
          check_flag = 1;
          ackData[0] = myData[0] * 11;
          radio.writeAckPayload (myData[0] - 1, &ackData, sizeof(ackData));
          value = 15;
          digitalWrite(red_led, 1);
          digitalWrite(green_led, 0);
        }
        break;

      case 3:
        if (!check_flag) {
          check_flag = 1;
          ackData[0] = myData[0] * 11;
          radio.writeAckPayload (myData[0] - 1, &ackData, sizeof(ackData));
          value = 15;
          digitalWrite(red_led, 1);
          digitalWrite(green_led, 0);
        }
        break;

      case 4:
        if (!check_flag) {
          check_flag = 1;
          ackData[0] = myData[0] * 11;
          radio.writeAckPayload (myData[0] - 1, &ackData, sizeof(ackData));
          value = 15;
          digitalWrite(red_led, 1);
          digitalWrite(green_led, 0);
        }
        break;

      case 5:
        ackData[0] = value;
        radio.writeAckPayload (myData[0] - 5, &ackData, sizeof(ackData));
        break;

      case 6:
        ackData[0] = value;
        radio.writeAckPayload (myData[0] - 5, &ackData, sizeof(ackData));
        break;

      case 7:
        ackData[0] = value;
        radio.writeAckPayload (myData[0] - 5, &ackData, sizeof(ackData));
        break;

      case 8:
        ackData[0] = value;
        radio.writeAckPayload (myData[0] - 5, &ackData, sizeof(ackData));
        break;

      default:
        break;
    }
  }
  butt = digitalRead(button);
  if (!butt && !butt_flag) {
    butt_flag = 1;
    check_flag = 0;
    value = 10;
    digitalWrite(red_led, 0);
    digitalWrite(green_led, 1);
  }
  if (butt && butt_flag) butt_flag = 0;
  if (radio.rxFifoFull()) radio.flush_tx();
}

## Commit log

2025-04-30 update all
    [Admin.fzz, Players (1-4).fzz]
2026-03-17 add kicad
    [BrainRing_Wireless_Admin.kicad_pcb, BrainRing_Wireless_Admin.kicad_sch, BrainRing_Wireless_Players.kicad_pcb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]
2026-03-17 upd sch
    [BrainRing_Wireless_Players.kicad_sch, Power Sheet.kicad_sch]
2026-03-18 add pcb2
    [BrainRing_Wireless_Admin.kicad_pcb, BrainRing_Wireless_Admin.kicad_sch, BrainRing_Wireless_Players.kicad_pcb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]
2026-06-05 change box and cap
    [BOX_PLAYERS.SLDASM, Box_BRw_players.3MF, Box_BRw_players.SLDPRT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]
2026-10-28 Refactor firmware: fair first-press detection, single player firmware, animations
    - Shared protocol/radio config (include/brainring.h) and non-blocking melody player (include/melody.h)
    - Admin: timestamp-based winner resolution with 30 ms decision window, reject pre-reset presses,
    fresh ACK payloads, press/reset sound and LED indication, idle breathing
    - Players: one firmware for all boards, ID/color stored in EEPROM with on-device color menu,
    reliable press delivery with per-ID retry delays, link-loss detection,
    strip + button LED (PWM) animations, 3 random win melodies and a lose melody
    - Admin case generator, print files and PCB updates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
2026-10-29 Players board Rev. 2.1: IP5305 keep-alive load
    - Schematic/PCB: AO3400A (Q2) + 47 Ohm load (R10), gate R8 100 / R9 100k,
    driven from U1 A3 — same circuit as the Admin board. Placed on B.Cu
    under the MCU module; main parts and case-related positions unchanged.
    - GND via enlarged to 1.6/0.8 mm for a top-side wire jumper to U1 GND.
    - Player firmware: 300 ms pulse every 15 s on A3 so IP5305 doesn't shut
    the 5V output down at light load.
    - Regenerated laser-printer sheets (B.Cu, mirrored F.Silkscreen).
2026-10-29 Admin case: update generator and print files
2026-10-31 Players box: print groove and inner shelf without supports
    Replace the flat groove ceiling and the 3 mm inner shelf with 45 deg
    surfaces so the ring prints unsupported. Groove floor (5.1 x 2 mm) is
    unchanged. Adds Groove_chamfer_45 and Shelf_cone_45 to the SolidWorks
    part, re-exports the STEP and adds a ready-to-slice Bambu project.
2026-10-31 Players case: update cap, remove old box project
2026-10-31 Players board: update print PDF, remove KiCad lock files
2026-11-06 Simon: auto countdown between rounds, red timeout warning, 10% brightness steps
    - Round flow: 1 s lights, 1 s pause, 2 s score, 3-2-1 countdown; admin click holds
    - Per-press timeout +1 s (4.4 s down to 2.5 s), first press +1 s
    - Strips fill red 20%->60% in the last 2 s before a timeout
    - Strip brightness 100%..20% in 10% steps, saved to EEPROM on each step
    - Radio power HIGH (medium), roster fixed at game start
    - Add Russian PDF instruction (docs/)
    - Update players box print project
2026-11-07 Firmware: fix radio cold start, Simon double press, 2 s result indication
    - Wait for NRF24 power-on reset before setup and verify config (no link after cold power-up)
    - Players: latch button after a press until stably released (bounce counted twice in Simon)
    - Win/lose indication limited to 2 s; losers stay dim red on any player color
    - Radio PA_LOW, IP5305 keep-alive pulse 600 ms
